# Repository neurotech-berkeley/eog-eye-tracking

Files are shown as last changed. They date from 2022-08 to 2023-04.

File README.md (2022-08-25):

# eog-eye-tracking
Exploration of EOG (electrooculogram) signals as a potential human computer interface.

## Project Description
This project was one of [Neurotech@Berkeley](https://github.com/neurotech-berkeley)'s Devices Division projects in Spring 2022. At Devices, we build hardware for the brain - to measure and analyze electrical signals generated by our bodies to see if we can come up with new ways to interact with computers. You can learn more about our organization as a whole at [neurotech.berkeley.edu](https://neurotech.berkeley.edu/).

Inspired by the potential that the gaze-tracking systems, we set out to explore a technique with substantially lower computational cost than computer vision: electrooculography (EOG). Unlike computer vision that relies on cameras, EOG relies on intrintic electric signals generated in our eye.

In this project, we prototyped, designed, fabricated, and tested analog front end (AFE) circuit to control a dinosaur chrome game. 

## Demo

In this demo, we connected our custom-designed PCB to a laptop through an Arduino. The dinosaur is controlled by blinks alone, hands and keyboard-free.

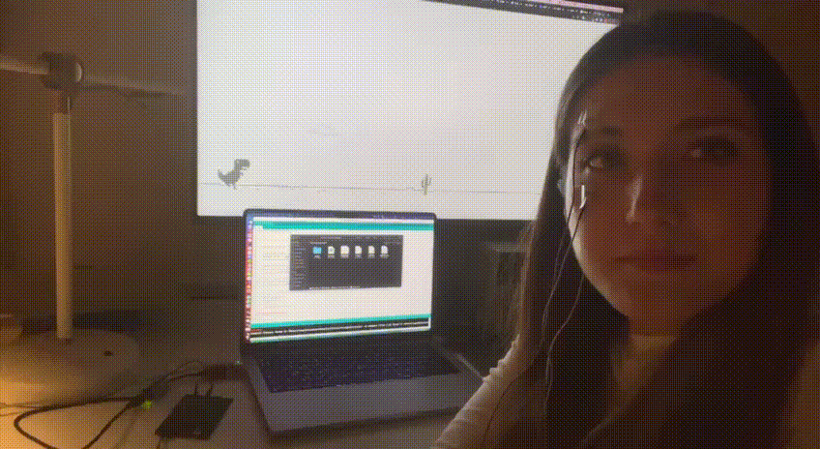
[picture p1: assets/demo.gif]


## Function Diagram
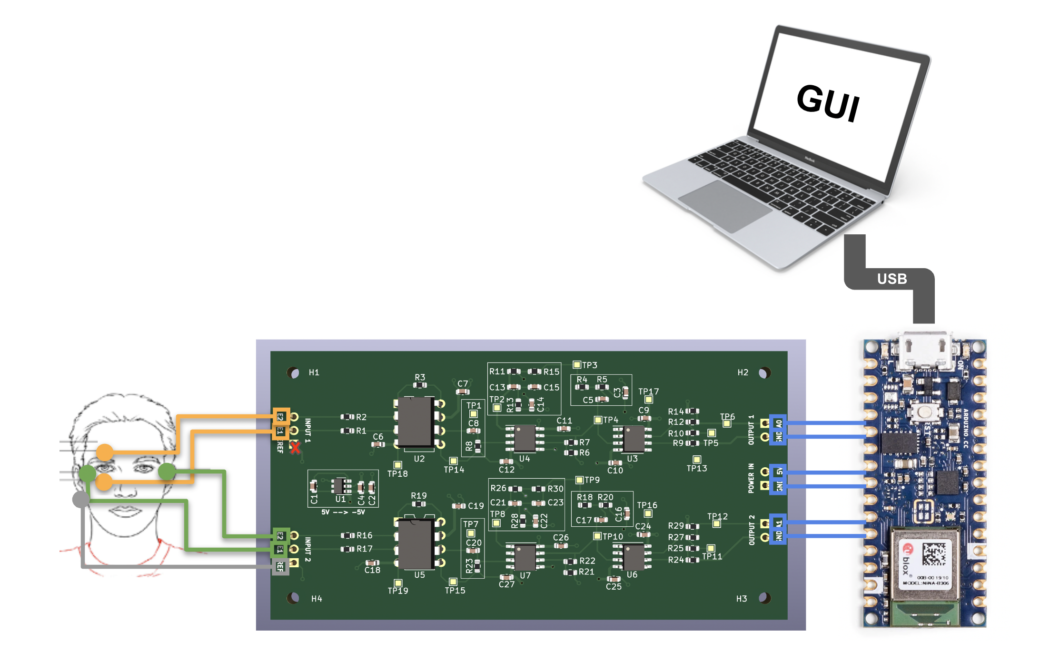
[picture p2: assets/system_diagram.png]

In this initial setup, we use three electrodes (2 attaching above and below an eye, and 1 fore reference behind an ear). These electrodes then attach to our PCB that amplify and filter from noise the difference between the two electrodes. The PCB is able to output a voltage acceptable by most 5V-operated microcontrollers (like Arduino, for example). The output of one channel is just an analog voltage that can be read by an onboard ADC on a microcontroller, which then can get transmitted to a laptop through a USB port for real-time analysis.

## Next Steps
Here are some potential improvements and ideas that we want to incorporate in future iterations of the design:

### 1. Add bluetooth capabilities
Currently, the PCB is communicating to the laptop through USB cable, but it would be cool to make it wireless! Open to exploring bluetooth chips other than Arduino. This would potentially mean exploring power consumption of the device and including a charging circuit.

### 2. Replace fixed resistors/capacitors with tunable alternatives
Currently, the AFE of our PCB is configured specifically for EOG signals, but it would be cool to make it adjustable to other types of signals by incorporating tunable resistors/capacitors in filters.

### 3. Incorporate a pattern recognition algorithm
Currently, we tell the difference between looking up and down by using basic thresholding :P

### 4. Build a chrome extension
Moving away from playing games, we want to explore incorporating eye tracking into an every-day workflow!

### 5. Build a dashboard for observing the signal in real-time

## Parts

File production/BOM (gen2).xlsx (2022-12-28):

Comment | Designator | Footprint | JLCPCB Part # (optional)
MAX764ESA+ | U8 | SOIC127P600X175-8N
47uH | L1 | IND_NRS6028T470M
MBRS330T3G | D1 | DIOM7959X261N
68uF | C4 | CAP_20TQC100MYF | C147772
100uF | C1 | CAP_20TQC100MYF | C139578
0.1uF, 25V | C2,C6,C7,C9,C10,C11,C12,C18,C19,C24,C25,C26,C27,C33 | C_0603_1608Metric | C83054
2k7, 1/10W, 0.5% | R15,R26,R30,R11 | R_0603_1608Metric | C227482
330R, 1/10W, 1% | R5 | R_0603_1608Metric | C23138
D5V0 | D5,D2,D3,D4 | R_0603_1608Metric
1k3, 1/10W, 1% | R13,R28 | R_0603_1608Metric | C22767
1uF, 50V | C13,C15,C21,C23 | C_0603_1608Metric | C15849
220k, 1/10W, 1% | R2,R17,R1,R16 | R_0603_1608Metric | C22961
150R, 1/10W, 1% | R4,R24 | R_0603_1608Metric | C22808
2.2uF, 25V | C14,C22 | C_0603_1608Metric | C57895
1k, 1/10W, 1% | R29,R12,R14,R27 | R_0603_1608Metric | C22797
10uF, 25V | C3,C5,C8,C16,C17,C20,C81,C82,C83,C201,C202,C203 | C_0603_1608Metric | C96446
2k2, 1/10W, 1% | R3,R19 | R_0603_1608Metric | C4190
LED | LED1 | LED_0603_1608Metric | C84266

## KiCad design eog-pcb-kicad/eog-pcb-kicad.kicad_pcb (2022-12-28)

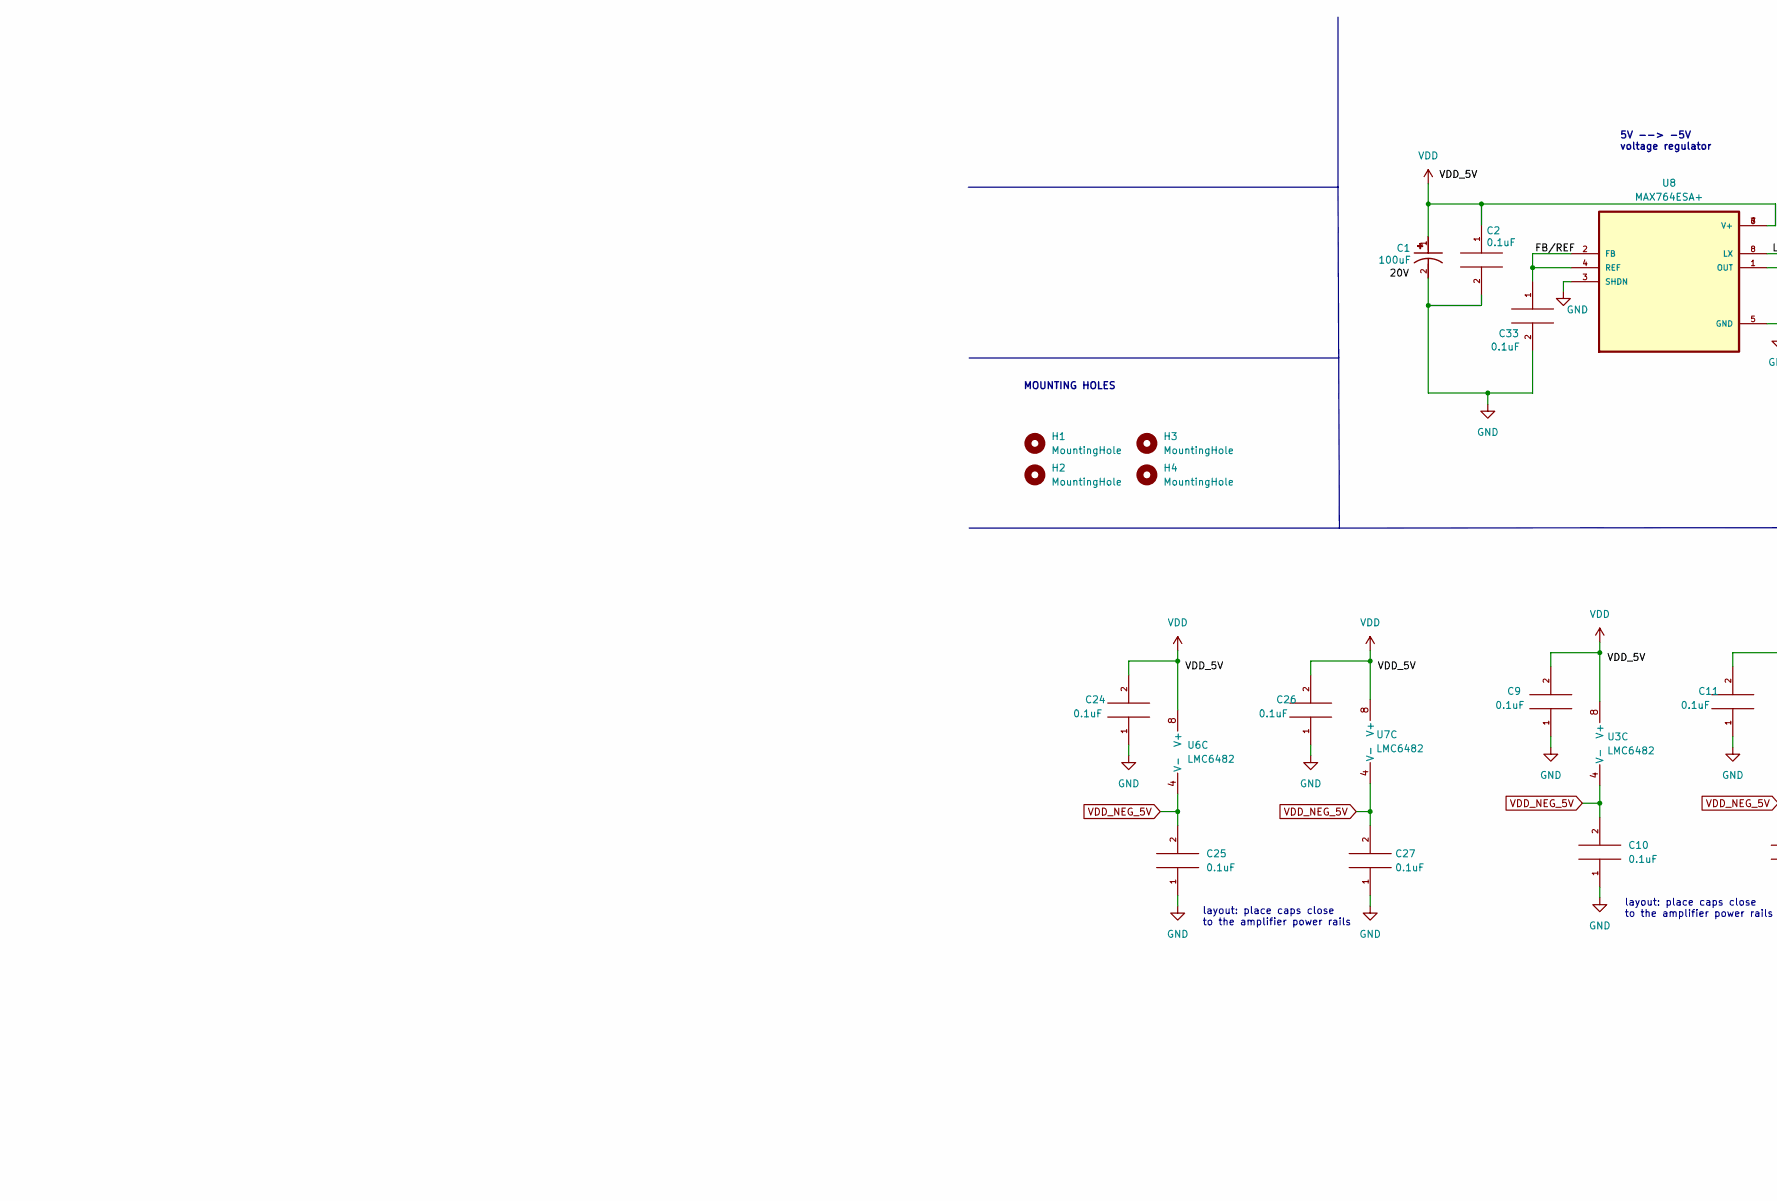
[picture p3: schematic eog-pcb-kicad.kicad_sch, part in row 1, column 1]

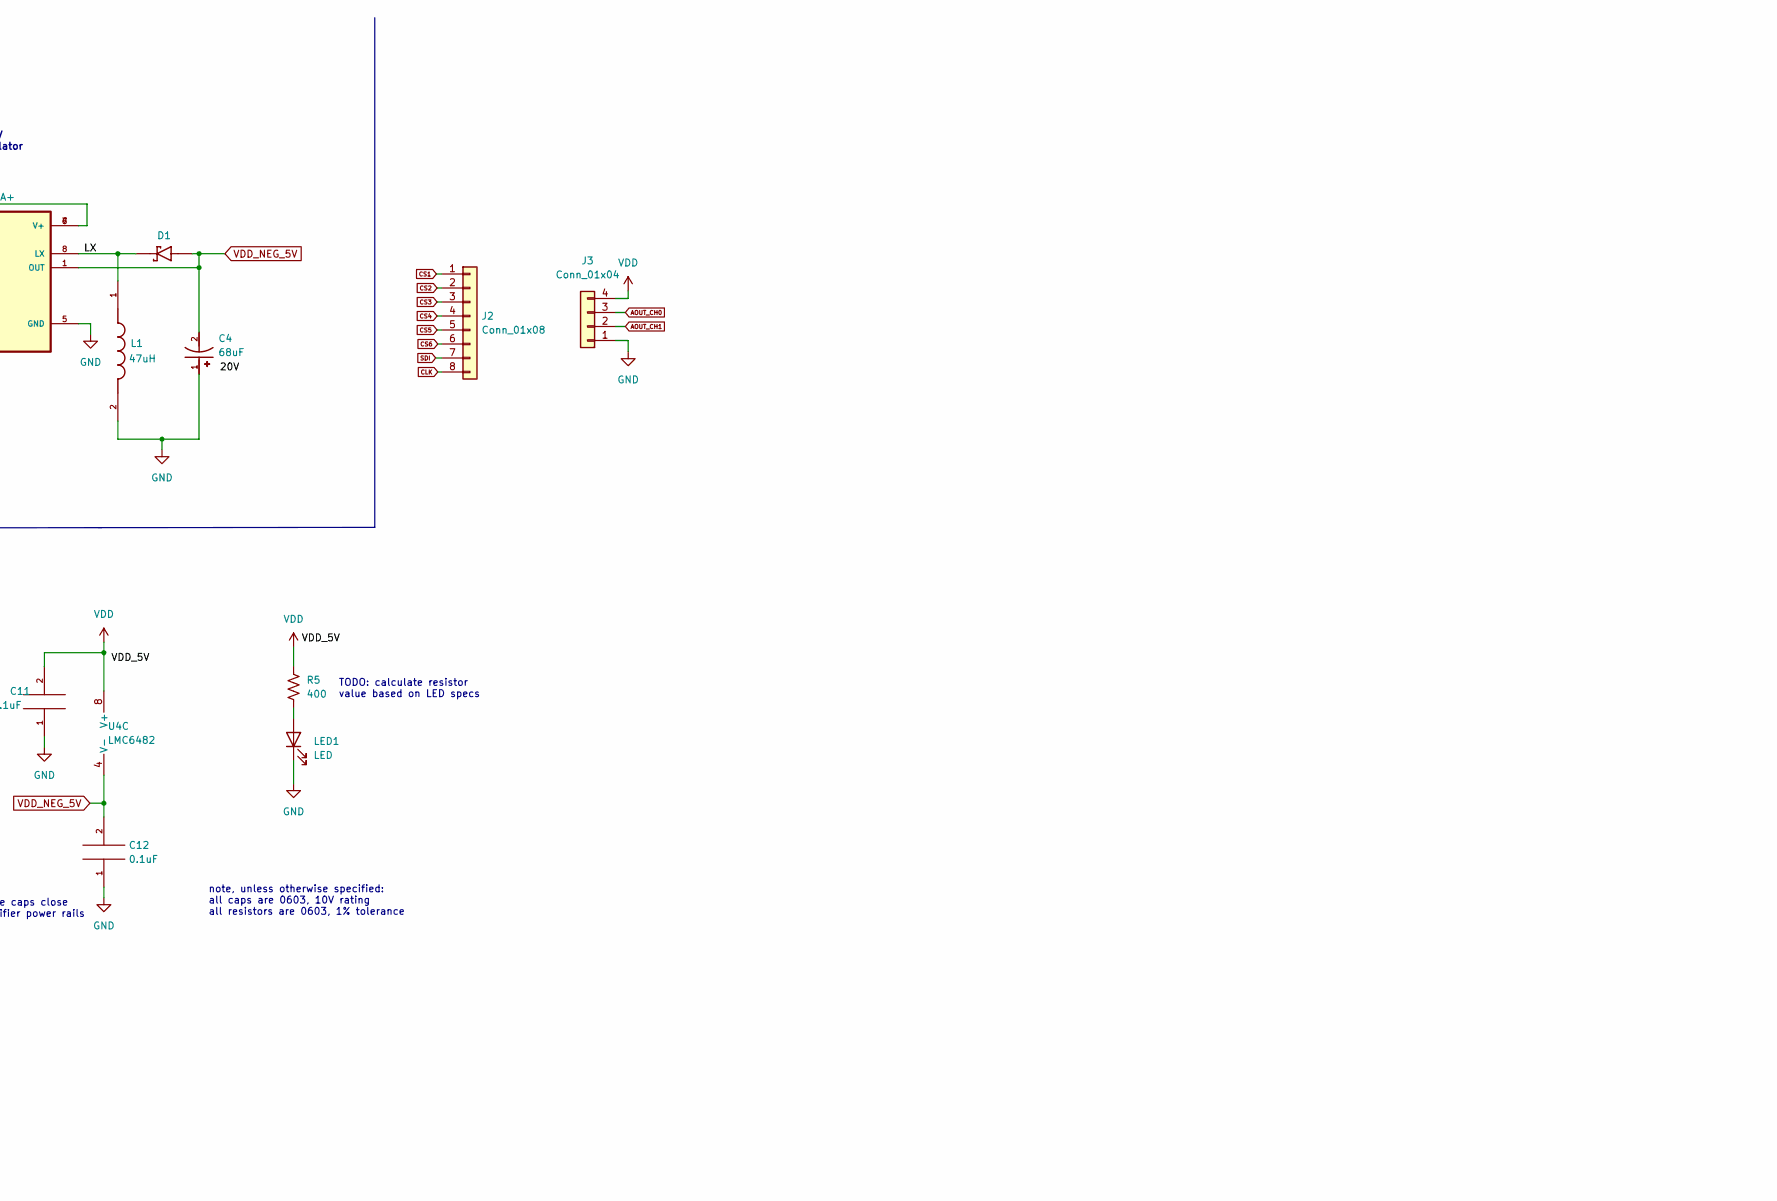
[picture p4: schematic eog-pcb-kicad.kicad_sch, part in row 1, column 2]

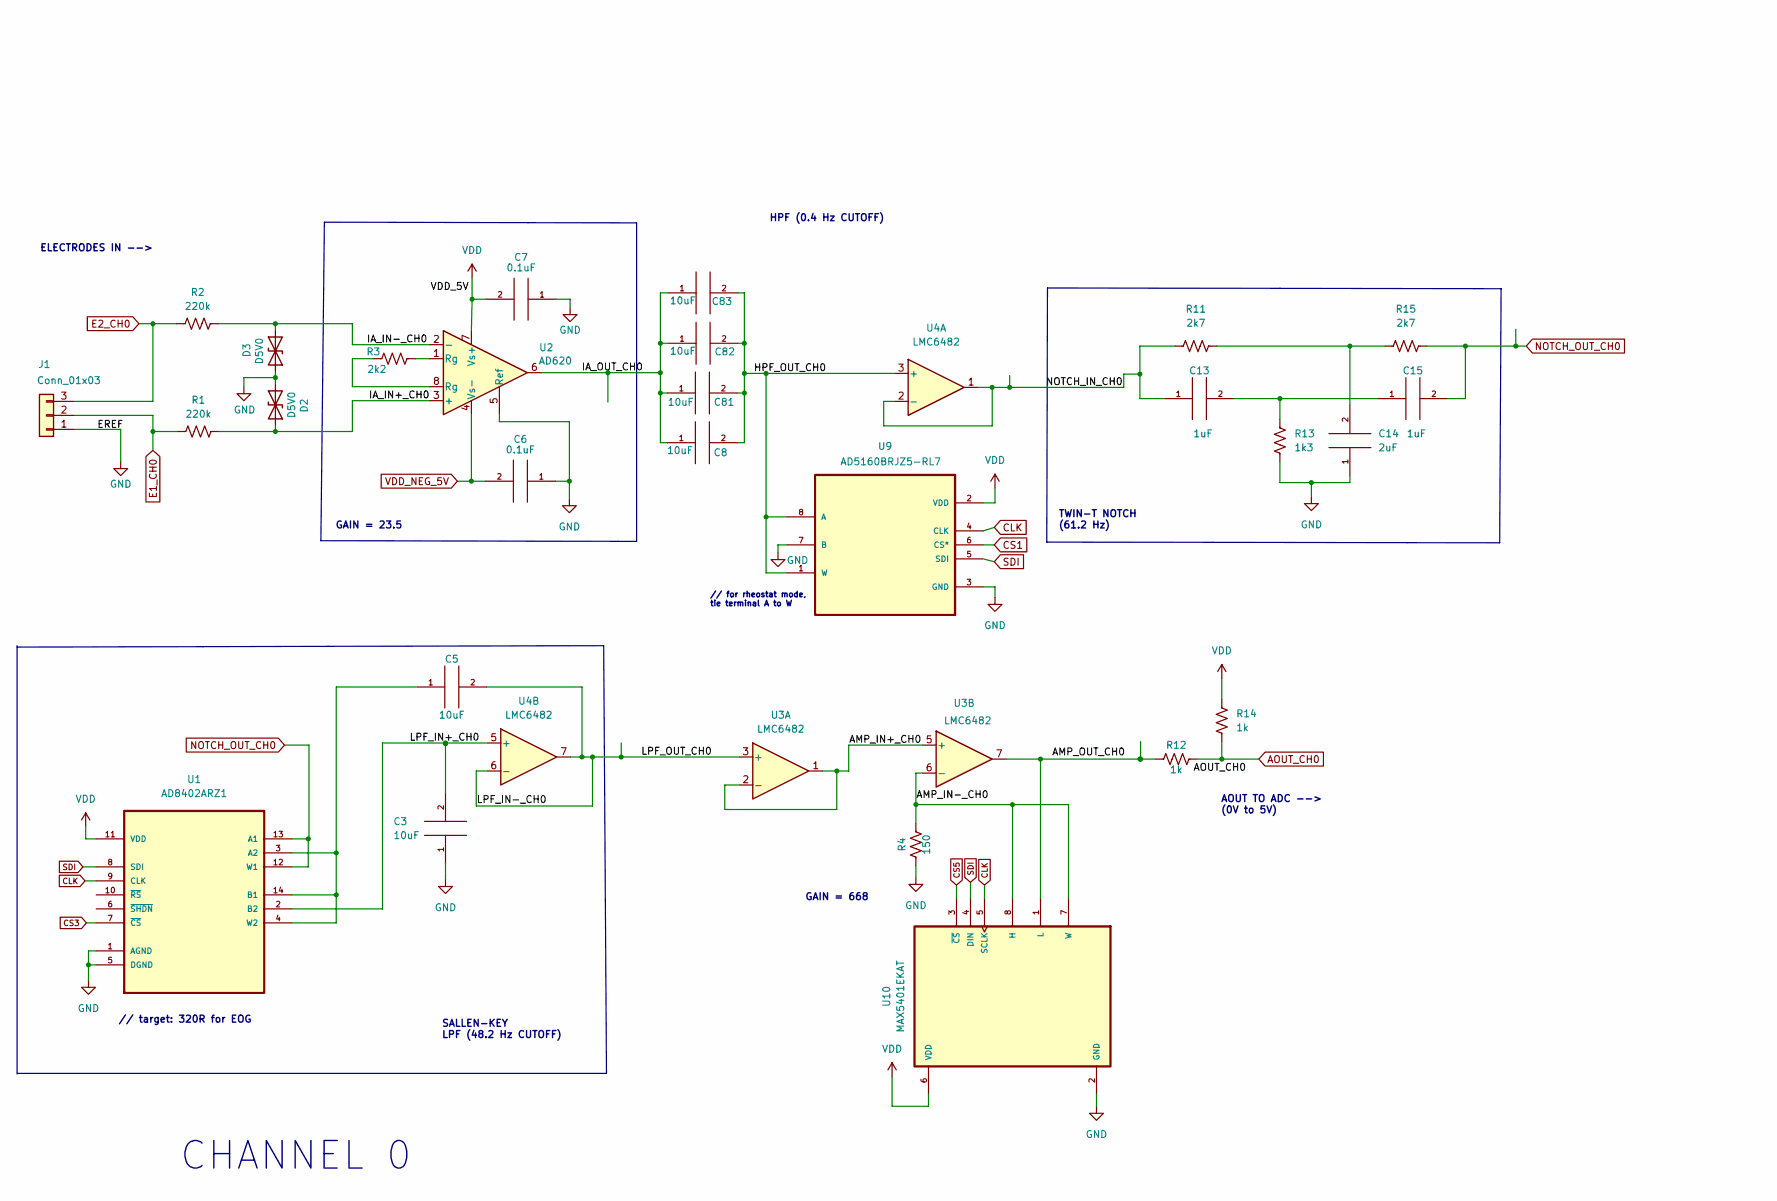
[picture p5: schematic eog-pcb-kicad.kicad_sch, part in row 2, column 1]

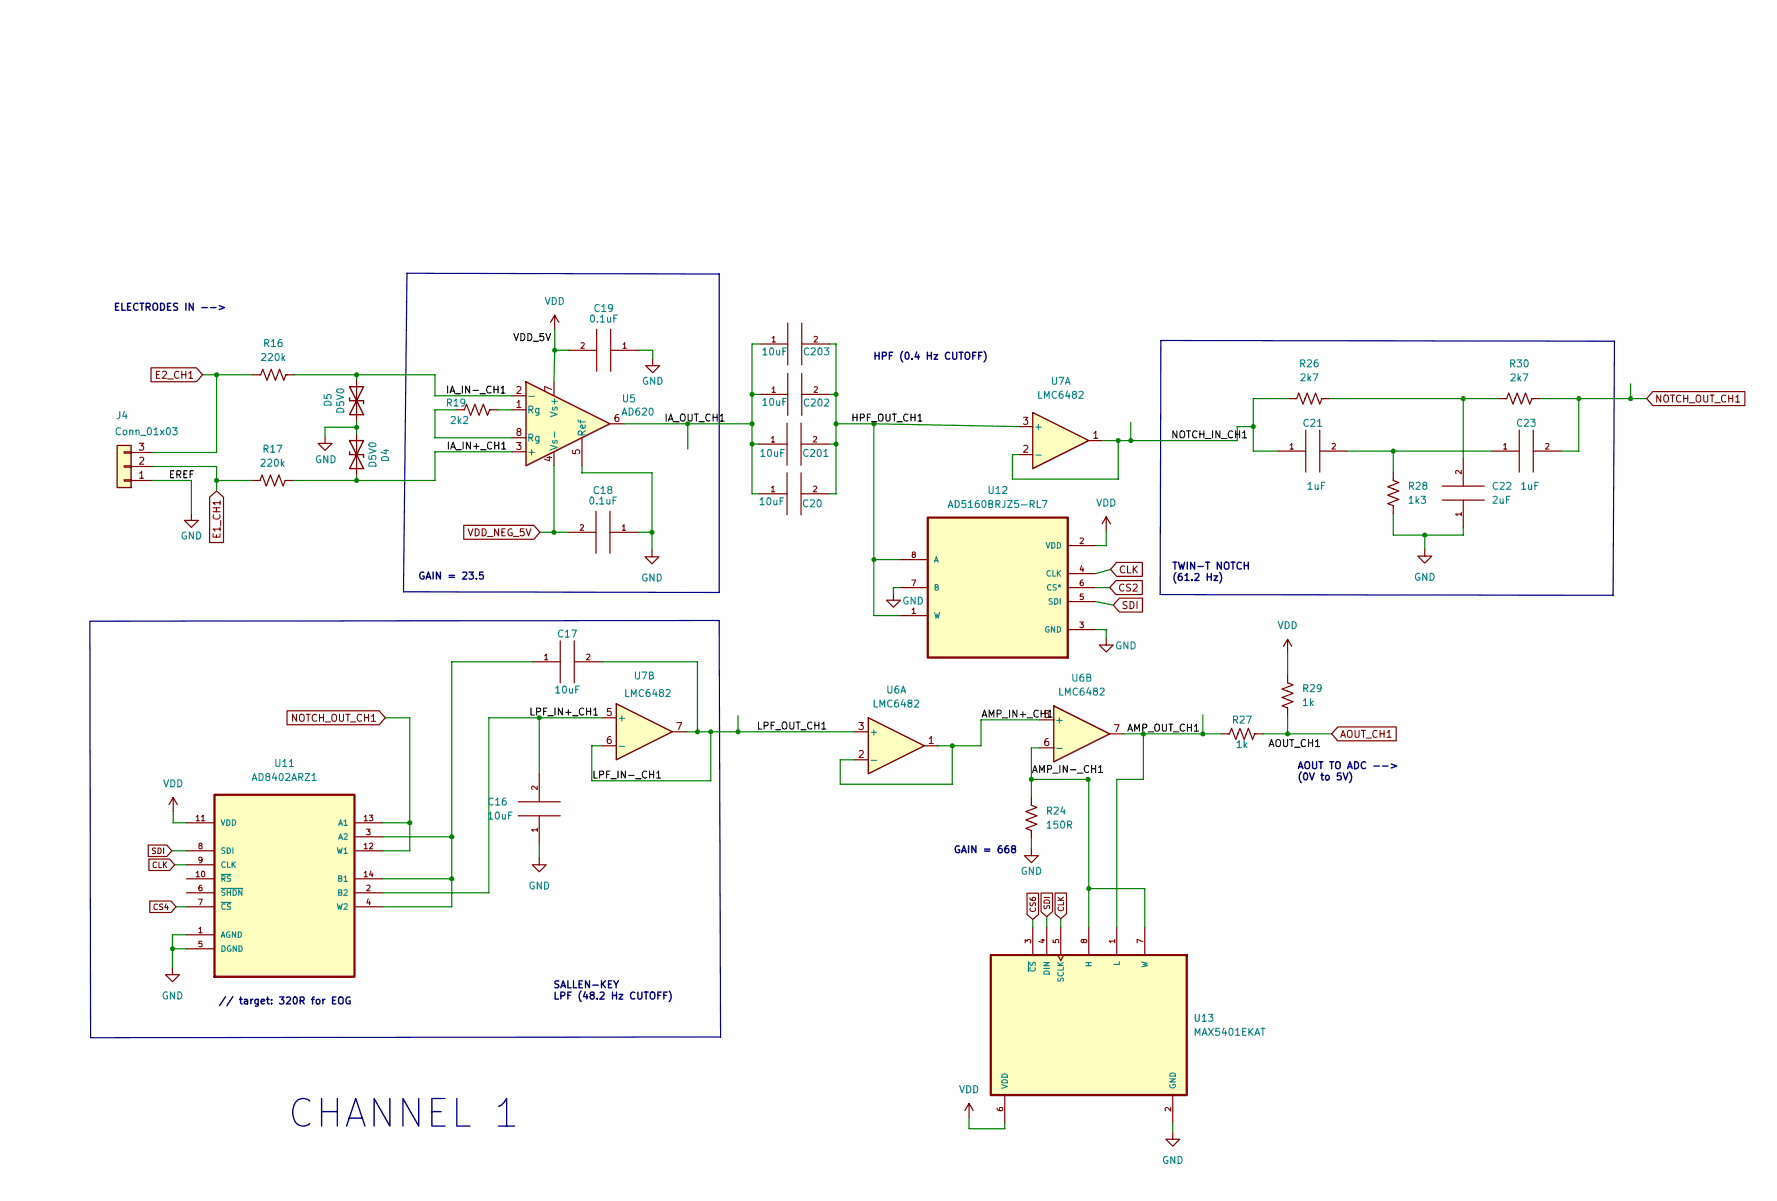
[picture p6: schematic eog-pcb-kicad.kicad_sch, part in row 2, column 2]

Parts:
C1: 100uF; CAP_20TQC100MYF; PARTREV 30-Nov-20
C2, C6, C7, C9, C10, C11, C12, C18, C19, C24, C25, C26, C27, C33: 0.1uF; C_0603_1608Metric
C3, C5, C8, C16, C17, C20, C81, C82, C83, C201, C202, C203: 10uF; C_0603_1608Metric
C4: 68uF; CAP_20TQC100MYF; PARTREV 30-Nov-20
C13, C15, C21, C23: 1uF; C_0603_1608Metric
C14, C22: 2uF; C_0603_1608Metric
D1: MBRS330T3G; DIOM7959X261N; PARTREV 14
D2, D3, D4, D5: D5V0; R_0603_1608Metric
H1, H2, H3, H4: MountingHole; MountingHole_2.2mm_M2
J1, J4: Conn_01x03; PinHeader_1x03_P2.54mm_Vertical
J2: Conn_01x08; PinHeader_1x08_P2.54mm_Vertical
J3: Conn_01x04; PinHeader_1x04_P2.54mm_Vertical
L1: 47uH; IND_NRS6028T470M; PARTREV N/A
LED1: LED; LED_0603_1608Metric
R1, R2, R16, R17: 220k; R_0603_1608Metric
R3, R19: 2k2; R_0603_1608Metric
R4: 150; R_0603_1608Metric
R5: 400; R_0603_1608Metric
R11, R15, R26, R30: 2k7; R_0603_1608Metric
R12, R14, R27, R29: 1k; R_0603_1608Metric
R13, R28: 1k3; R_0603_1608Metric
R24: 150R; R_0603_1608Metric
U1, U11: AD8402ARZ1; SOIC-14_3.9x8.7mm_P1.27mm; MPN AD8402ARZ1
U2, U5: AD620; SOIC-8_3.9x4.9mm_P1.27mm
U3, U4, U6, U7: LMC6482; SOIC-8_3.9x4.9mm_P1.27mm
U8: MAX764ESA+; SOIC-8_3.9x4.9mm_P1.27mm
U9, U12: AD5160BRJZ5-RL7; SOT-23-8; MPN AD5160BRJZ5-RL7
U10, U13: MAX5401EKAT; SOT-23-8

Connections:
/AMP_IN+_CH0: U3.1, U3.2 (-), U3.5 (+)
/AMP_IN+_CH1: U6.1, U6.2 (-), U6.5 (+)
/AMP_IN-_CH0: R4.1, U3.6 (-), U10.7 (W), U10.8 (H)
/AMP_IN-_CH1: R24.2, U6.6 (-), U13.7 (W), U13.8 (H)
/AMP_OUT_CH1: R27.2, U6.7, U13.1 (L)
/FB/REF: C33.1, U8.2 (FB), U8.4 (REF)
/HPF_OUT_CH0: C8.2, C81.2, C82.2, C83.2, U4.3 (+), U9.1 (W), U9.8 (A)
/HPF_OUT_CH1: C20.2, C201.2, C202.2, C203.2, U7.3 (+), U12.1 (W), U12.8 (A)
/IA_IN+_CH0: D2.2 (A2), R1.2, U2.3 (+)
/IA_IN+_CH1: D4.2 (A2), R17.2, U5.3 (+)
/IA_IN-_CH0: D3.2 (A2), R2.2, U2.2 (-)
/IA_IN-_CH1: D5.2 (A2), R16.2, U5.2 (-)
/IA_OUT_CH0: C8.1, C81.1, C82.1, C83.1, U2.6
/IA_OUT_CH1: C20.1, C201.1, C202.1, C203.1, U5.6
/LPF_IN+_CH0: C3.2, U1.2 (B2), U4.5 (+)
/LPF_IN+_CH1: C16.2, U7.5 (+), U11.2 (B2)
/LPF_IN-_CH0: C5.2, U3.3 (+), U4.6 (-), U4.7
/LPF_IN-_CH1: C17.2, U6.3 (+), U7.6 (-), U7.7
/LX: D1.C, L1.1, U8.8 (LX)
/NOTCH_IN_CH0: C13.1, R11.2, U4.1, U4.2 (-)
/NOTCH_IN_CH1: C21.1, R26.2, U7.1, U7.2 (-)
AOUT_CH0: J3.3, R12.1, R14.1
AOUT_CH1: J3.2, R27.1, R29.1
CLK: J2.8, U1.9 (CLK), U9.4 (CLK), U10.5 (SCLK), U11.9 (CLK), U12.4 (CLK), U13.5 (SCLK)
CS1: J2.1, U9.6 (CS*)
CS2: J2.2, U12.6 (CS*)
CS3: J2.3, U1.7 (~CS)
CS4: J2.4, U11.7 (~CS)
CS5: J2.5, U10.3 (~CS)
CS6: J2.6, U13.3 (~CS)
E1_CH0: J1.2, R1.1
E1_CH1: J4.2, R17.1
E2_CH0: J1.3, R2.1
E2_CH1: J4.3, R16.1
GND: C1.2, C2.2, C3.1, C4.1, C6.1, C7.1, C9.1, C10.1, C11.1, C12.1, C14.1, C16.1, C18.1, C19.1, C22.1, C24.1, C25.1, C26.1, C27.1, C33.2, D2.1 (A1), D3.1 (A1), D4.1 (A1), D5.1 (A1), J1.1, J3.1, J4.1, L1.2, LED1.1 (K), R4.2, R13.2, R24.1, R28.2, U1.1 (AGND), U1.5 (DGND), U2.5 (Ref), U5.5 (Ref), U8.3 (SHDN), U8.5 (GND), U9.3 (GND), U9.7 (B), U10.2 (GND), U11.1 (AGND), U11.5 (DGND), U12.3 (GND), U12.7 (B), U13.2 (GND)
NOTCH_OUT_CH0: C15.2, R15.1, U1.12 (W1), U1.13 (A1)
NOTCH_OUT_CH1: C23.2, R30.1, U11.12 (W1), U11.13 (A1)
unnamed: C5.1, U1.3 (A2), U1.4 (W2), U1.14 (B1)
unnamed: C13.2, C15.1, R13.1
unnamed: C14.2, R11.1, R15.2
unnamed: C17.1, U11.3 (A2), U11.4 (W2), U11.14 (B1)
unnamed: C21.2, C23.1, R28.1
unnamed: C22.2, R26.1, R30.2
unnamed: LED1.2 (A), R5.2
unnamed: R3.1, U2.1 (Rg)
unnamed: R3.2, U2.8 (Rg)
unnamed: R12.2, U3.7, U10.1 (L)
unnamed: R19.1, U5.1 (Rg)
unnamed: R19.2, U5.8 (Rg)
SDI: J2.7, U1.8 (SDI), U9.5 (SDI), U10.4 (DIN), U11.8 (SDI), U12.5 (SDI), U13.4 (DIN)
VDD: C1.1, C2.1, C7.2, C9.2, C11.2, C19.2, C24.2, C26.2, J3.4, R5.1, R14.2, R29.2, U1.11 (VDD), U2.7 (Vs+), U3.8 (V+), U4.8 (V+), U5.7 (Vs+), U6.8 (V+), U7.8 (V+), U8.6 (V+), U8.7 (V+), U9.2 (VDD), U10.6 (VDD), U11.11 (VDD), U12.2 (VDD), U13.6 (VDD)
VDD_NEG_5V: C4.2, C6.2, C10.2, C12.2, C18.2, C25.2, C27.2, D1.A, U2.4 (Vs-), U3.4 (V-), U4.4 (V-), U5.4 (Vs-), U6.4 (V-), U7.4 (V-), U8.1 (OUT)

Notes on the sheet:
GAIN = 23.5
ELECTRODES IN -->
CHANNEL 1
TWIN-T NOTCH (61.2 Hz)
// target: 320R for EOG
AOUT TO ADC --> (0V to 5V)
TODO: calculate resistor value based on LED specs
MOUNTING HOLES
HPF (0.4 Hz CUTOFF)
layout: place caps close to the amplifier power rails
CHANNEL 0
GAIN = 668
note, unless otherwise specified: all caps are 0603, 10V rating all resistors are 0603, 1% tolerance
5V --> -5V voltage regulator
SALLEN-KEY LPF (48.2 Hz CUTOFF)
// for rheostat mode, tie terminal A to W

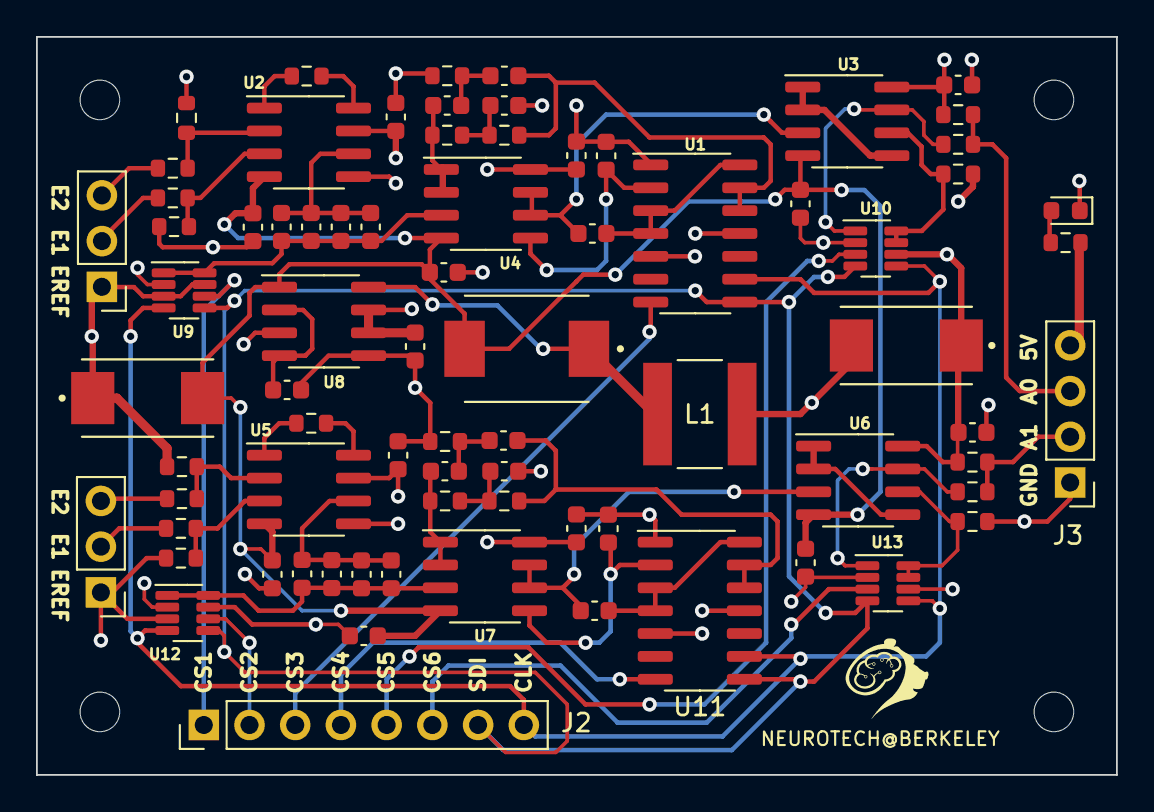
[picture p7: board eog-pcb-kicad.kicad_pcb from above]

Board: 4 copper layers, 60.0 x 41.0 mm, 81 parts (0 on the bottom side), 52 nets.

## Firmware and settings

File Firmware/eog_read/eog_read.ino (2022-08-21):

/*
 * This code is for reading analog signals coming from EOG recording 
board.
 * Currently, it detects (by thresholding) player's eye movements and 
sends 
 * a corresponding keystroke via USB
 */

#include "PluggableUSBHID.h"
#include "USBKeyboard.h"

#define VERTICAL_CH_PIN A0
#define HORIZONTAL_CH_PIN A1

/*
 * CONFIG VARIABLES, FEEL FREE TO CHANGE
 */
int sampling_period = 5; // how many times do we sample per second

int window_width_ms = 1000; // in milliseconds, for moving average
int window_width_samples_num = window_width_ms / sampling_period;
int window_array[200]; // defining window for moving average

int baseline_duration_ms = 5000; // in milliseconds, recording the 
baseline average voltage when steady
int baseline_duration_samples_num = baseline_duration_ms / 
sampling_period;
int baseline_array[1000]; // defining array for storing baseline readings

unsigned long current_time;
int vertical_reading = 0;
int horizontal_reading = 0;

unsigned long start_time;
int i = 0;
int running_sum = 0;
int baseline = 0;

bool calibrating = true;//  

USBKeyboard Keyboard;

void setup() {
  Serial.begin(115200);
  pinMode(VERTICAL_CH_PIN, INPUT);
  pinMode(HORIZONTAL_CH_PIN, INPUT);

  delay(3000);  
  start_time = millis();
}

void loop() {  
  if (calibrating) {
    if (millis() < start_time + baseline_duration_ms) {
      vertical_reading = analogRead(VERTICAL_CH_PIN);
      baseline_array[i] = vertical_reading;
      running_sum += vertical_reading;
      i += 1;
    }
    else {
      calibrating = false;
      baseline = running_sum / baseline_duration_samples_num; // computing 
the baseline
      Serial.println("baseline:");
      Serial.println(baseline);
    }
  } 
  else {
    vertical_reading = analogRead(VERTICAL_CH_PIN);
    Serial.println(vertical_reading);
    if (vertical_reading > 1000) {
      Serial.println("up");  
      Keyboard.printf(" ");
      delay(50);
    }
  }
  delay(3);
}

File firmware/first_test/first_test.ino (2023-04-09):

#define VERTICAL_CH_PIN A0
#define HORIZONTAL_CH_PIN  A1
int vertical_reading = 0;
int horizontal_reading = 0;
//int time = 0;
void setup() {
  Serial.begin(9600);
}

void loop() {
  vertical_reading = analogRead(VERTICAL_CH_PIN);
  horizontal_reading = analogRead(HORIZONTAL_CH_PIN);
  
  Serial.print(vertical_reading);
  Serial.println(" ");
  Serial.print(-200);
  Serial.print(" ");
  Serial.print("1200");
  Serial.print(" ");
}

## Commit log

2022-08-21 adding PCB and production files
    [channel_1.kicad_sch, channel_2.kicad_sch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]
2022-08-21 adding firmware files to upload to Arduino
2022-10-30 add calibration testing
2022-11-18 added libraries for digipots and started reorganizing the pcb for 2nd version
    [eog-pcb-kicad.kicad_pcb, eog-pcb-kicad.kicad_sch]
2022-11-23 progress on layout
    [eog-pcb-kicad.kicad_pcb]
2022-12-28 gen2 board is ready and production files are generated
    [eog-pcb-kicad-B_Cu.gbl, eog-pcb-kicad-B_Cu.gbr, eog-pcb-kicad-B_Mask.gbr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]
2022-12-28 updating BOM and CPL files
    [BOM (gen2).xlsx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]
2023-01-08 adding the arduino script for testing new pcb boards
    [eog-pcb-kicad.kicad_sch]
2023-03-06 added framework for grpc
